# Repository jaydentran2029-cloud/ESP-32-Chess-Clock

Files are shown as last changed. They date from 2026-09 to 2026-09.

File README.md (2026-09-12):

# ESP32 Dual-OLED Chess Clock

ESP32_Chess_Clock

A digital chess clock built using an ESP32, two OLED displays, and arcade microswitches.

## Features & Game Logic
* **Independent Displays:** Uses the U8g2 SW I2C implementation to run two 0.96" OLEDs that share the same default hardware address.
* **Turn Management:** Pressing the active player's button pauses their timer and instantly starts the opponent's timer.
* **Time Control:** Standard base time countdown.
* **Timeout Condition:** If a timer reaches zero, the display flags "Out of Time". This results in a loss on time, subject to standard chess rules regarding insufficient material.
* **Internal Pull-ups:** Uses the ESP32's internal pull-up resistors (`INPUT_PULLUP`) for the arcade buttons, removing the need for external resistors.

## Hardware & Engineering
* 1x ESP32 Development Board
* 2x SSD1306 0.96" I2C OLED Displays
* 2x Arcade Buttons with Microswitches
* Female-to-Female Jumper Wires
* Custom 3D Printed Enclosure

**Hardware Fix:** Encountered unreliable physical pin contact on the lower ESP32 header. Solved the intermittent signal issue by bypassing loose contact points using female-to-female jumper wire connections, ensuring stable operation during fast physical button presses.

## Wiring Configuration

| Component | ESP32 Pin | Note |
| :--- | :--- | :--- |
| Screen 1 | SDA = 21, SCL = 22 | Powered via 3.3V / GND |
| Screen 2 | SDA = 32, SCL = 33 | Powered via 3.3V / GND |
| Button 1 | Pin 14 | Connect NO to Pin 14, COM to GND |
| Button 2 | Pin 27 | Connect NO to Pin 27, COM to GND |

## Build Instructions
1. Clone this repository.
2. Open the project folder in Visual Studio Code with the **PlatformIO** extension installed.
3. The OLED displays require the `U8g2` library.
4. Connect the ESP32 via USB-C.
5. Click the Upload button (the right-pointing arrow `→`) on the bottom PlatformIO status bar to compile and flash the board.
6. Press either arcade button to start the timers.

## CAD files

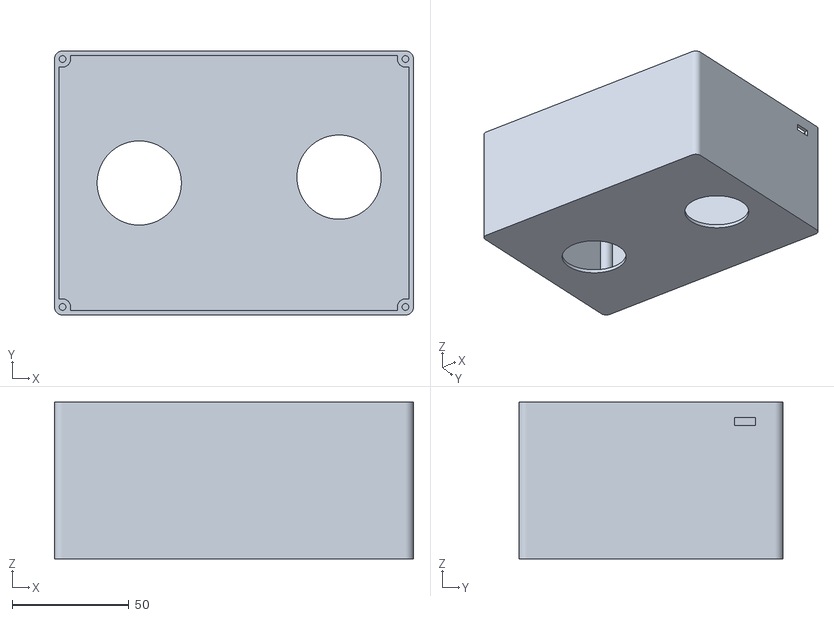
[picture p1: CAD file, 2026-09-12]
cad/Top Enclosure.stl
153.5 x 112.9 x 67.0

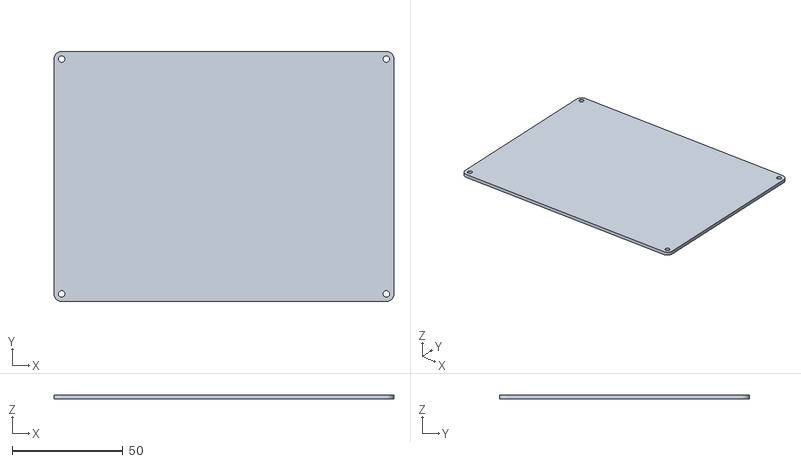
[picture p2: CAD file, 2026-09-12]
cad/Bottom Enclosure.stl
153.5 x 112.9 x 2.00

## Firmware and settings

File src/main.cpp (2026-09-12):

#include <Arduino.h>
#include <U8g2lib.h>

// By using SW_I2C (Software I2C), we can assign the displays to any pins we want
// without worrying about the ESP32's internal hardware conflicts

// Screen 1 (Player 1)
// clock (SCL) = 22, data (SDA) = 21
U8G2_SSD1306_128X64_NONAME_F_SW_I2C screen1(U8G2_R0, /* clock=*/ 22, /* data=*/ 21, /* reset=*/ U8X8_PIN_NONE);

// Screen 2 (Player 2)
// clock (SCL) = 33, data (SDA) = 32
U8G2_SSD1306_128X64_NONAME_F_SW_I2C screen2(U8G2_R0, /* clock=*/ 33, /* data=*/ 32, /* reset=*/ U8X8_PIN_NONE);

#define BTN1_PIN 14
#define BTN2_PIN 27

// Game Settings 
long p1_time_ms = 5 * 60 * 1000; // 5 minutes (in milliseconds)
long p2_time_ms = 5 * 60 * 1000;

// 0 = Paused/Not started, 1 = Player 1's clock is ticking, 2 = Player 2's clock is ticking
int active_player = 0; 
unsigned long last_update_time = 0;

void setup() {
  Serial.begin(115200);
  
  pinMode(BTN1_PIN, INPUT_PULLUP);
  pinMode(BTN2_PIN, INPUT_PULLUP);

  screen1.begin();
  screen2.begin();
}

// A helper function to draw the time on a specific screen
void drawTime(U8G2 &screen, long time_ms, bool isActive) {
  screen.clearBuffer();
  
  if (time_ms < 0) time_ms = 0; // Don't go below zero
  
  // Math to figure out minutes, seconds, and tenths of a second
  int seconds = (time_ms / 1000) % 60;
  int minutes = (time_ms / 60000);
  int tenths = (time_ms / 100) % 10;

  char timeStr[10];
  if (minutes > 0) {
    // If over a minute, show MM:SS
    sprintf(timeStr, "%d:%02d", minutes, seconds);
  } else {
    // If under a minute, show SS.d 
    sprintf(timeStr, "%02d.%d", seconds, tenths); 
  }

  screen.setFont(u8g2_font_logisoso28_tr); 
  
  // Center the text on the screen
  int width = screen.getStrWidth(timeStr);
  int x = (128 - width) / 2;
  screen.drawStr(x, 45, timeStr);
  
  // Show whose turn it is
  if (isActive) {
    screen.setFont(u8g2_font_ncenB08_tr);
    screen.drawStr(25, 60, "YOUR TURN");
  } else if (time_ms == 0) {
    screen.setFont(u8g2_font_ncenB08_tr);
    screen.drawStr(20, 60, "OUT OF TIME!");
  }

  screen.sendBuffer();
}

void loop() {
  // Calculate how much time has passed since the last exact loop
  unsigned long current_time = millis();
  unsigned long delta = current_time - last_update_time;
  last_update_time = current_time;

  int btn1 = digitalRead(BTN1_PIN);
  int btn2 = digitalRead(BTN2_PIN);

  // If a player presses their button, the next player's turn begins
  if (btn1 == LOW && active_player != 2) {
    active_player = 2; 
  }
  if (btn2 == LOW && active_player != 1) {
    active_player = 1; 
  }

  // Player's clock shows in milliseconds when under a minute left on their clock. 
  if (active_player == 1) {
    p1_time_ms -= delta;
    if (p1_time_ms <= 0) {
      p1_time_ms = 0;
      active_player = 0; // Game over
    }
  } else if (active_player == 2) {
    p2_time_ms -= delta;
    if (p2_time_ms <= 0) {
      p2_time_ms = 0;
      active_player = 0; // Game over
    }
  }

  // Update both screens
  drawTime(screen1, p1_time_ms, active_player == 1);
  drawTime(screen2, p2_time_ms, active_player == 2);
  }

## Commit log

2026-09-05 Initial commit: ESP32 Chess Clock hardware and software complete
2026-09-12 Add image to README for ESP32 Chess Clock
    Added an image of the ESP32 Chess Clock to the README.
2026-09-12 Fix formatting of Upload button instruction in README
2026-09-12 Create CAD
2026-09-13 Rename Part Studio 1 - Part 1.stl to Top Enclosure.stl
    [top_enclosure.stl]
2026-09-13 Rename Part Studio 1 - Part 2.stl to Bottom Enclosure.stl
    [Bottom Enclosure.stl]
2026-09-13 Rename top_enclosure.stl to Top Enclosure.stl
    [Top Enclosure.stl]
2026-09-13 Move CAD files into cad folder
    [Bottom Enclosure.stl, Top Enclosure.stl]
